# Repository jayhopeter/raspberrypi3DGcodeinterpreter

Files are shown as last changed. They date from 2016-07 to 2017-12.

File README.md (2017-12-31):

# raspberrypi3DGcodeinterpreter
Work in Process code for a completely RaspberryPi controlled RepRap.  Thanks to Xiang Zhai for supplying his laser engraver gcode interpreter which I am using as a starting point for this project.

We have this system working with the code(It can be done without an Ardruino!).  Prints are not perfect but pretty close at this point. I will be updating the design to use an ADC chip instead of the ganky 555 timer high pulse measuring method I'm using now.

I will be uploading the Eagle schematic and soon as I get it cleaned up and matching the recent changes.

Current limitations:

- For testing purposing full stepping the motors is the only option. I'm not using stepsticks, I built my own controllers using L298 Quad-HBridge chips.  I also use a Hex inverter(NOT-GATE) to allow control with only 2 GPIOs instead of 4 for each motor, the trade off is that you can only full step your motors.  If you want to try without the NOT-GATE method or with half stepping you can change the commented out lines in the Bipolar Stepper Motor Class file.

*Update - Work has begun on a Windows IoT version of this software which will be written in C#.  I will link to it when it's published.

*Update - Will not be working on the Windows IoT version until the Microsoft makes the IoT OS more user friendly.

*Update - Bahamuttg is working on C++ version of the software with a complete UI in Qt C++ called PiRinter3D.  This will be for an all in one 3D Printing solution using the Raspberry PI(design, slicing, and printing).

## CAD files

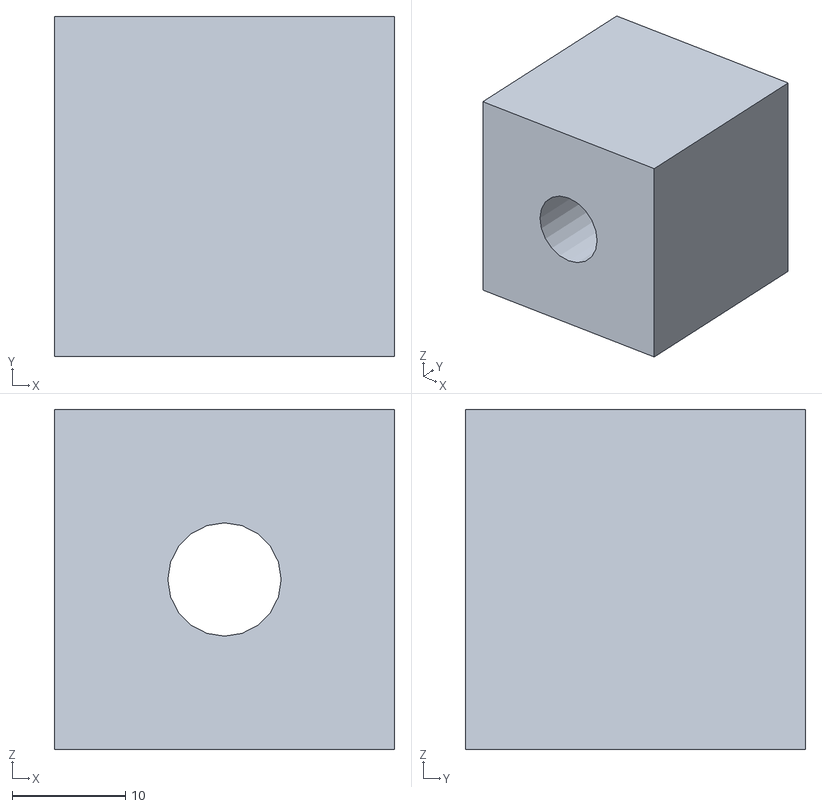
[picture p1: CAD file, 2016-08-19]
Gcode/testcube.STL
30.0 x 30.0 x 30.0

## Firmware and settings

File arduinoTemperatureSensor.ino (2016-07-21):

int sensorPin = A0;    // select the input pin for the potentiometer
int ledPin = 13;      // select the pin for the LED
int sensorValue = 0;  // variable to store the value coming from the sensor
int ctr = 1;
int sensortotal=0;
int maxTemp = 450;

void setup() {
  // declare the ledPin as an OUTPUT:
  pinMode(ledPin, OUTPUT);  
  Serial.begin(9600); 
}

void loop() {
  if (Serial.available() > 0) {
   // read the incoming tempsetting
   maxTemp = Serial.read();
  }
  // read the value from the sensor:
  sensorValue = analogRead(sensorPin);    
  // turn the ledPin on
  //Serial.println(sensorValue);
  
  sensortotal += sensorValue;
  //Serial.println(sensortotal);
  if( ctr % 10 == 0)
  {
    
  sensorValue = sensortotal/10;
  //Serial.println(sensorValue);
  //the quick way
  // map it to the range of the analog out:
  int outputValue = 0;
  outputValue = map(sensorValue, maxTemp-20, maxTemp, 0, 255);
  // change the analog out value:
  analogWrite(ledPin, outputValue);
  
  //the dumb way
//  if(sensorValue <= maxTemp-20)
//  {
//    analogWrite(ledPin,0);
//  }
//  else if(sensorValue > maxTemp-20 && sensorValue <= maxTemp-17)
//  {
//    analogWrite(ledPin,30);
//  }
//  else if(sensorValue > maxTemp-17 && sensorValue <= maxTemp-14)
//  {
//    analogWrite(ledPin,60);
//  }
//  else if(sensorValue > maxTemp-14 && sensorValue <= maxTemp-11)
//  {
//    analogWrite(ledPin,100);
//  }
//  else if(sensorValue > maxTemp-11 && sensorValue <= maxTemp-8)
//  {
//    analogWrite(ledPin,125);
//  }
//  else if(sensorValue > maxTemp-8 && sensorValue <= maxTemp-5)
//  {
//    analogWrite(ledPin,170);
//  }
//  else if(sensorValue > maxTemp-5 && sensorValue<= maxTemp)
//  {
//    analogWrite(ledPin,205);
//  }
//  else if(sensorValue > maxTemp)
//  {
//    analogWrite(ledPin,250);
//  }
  
  sensortotal = 0;
  ctr = 0;
  }
  ctr += 1;
  delay(20);                  
}

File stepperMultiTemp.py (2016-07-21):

#!/usr/bin/env python
# -*- coding: utf-8 -*-

# vim: tabstop=4 expandtab shiftwidth=4 softtabstop=4

# For input pins on motor controller using two GPIOs per motor.
# This tested with a TI 7404 HEX INVERTER and with 2 TI 754410
# and 2 L298N Dual H Bridges


import RPi.GPIO as GPIO
import time
GPIO.setmode(GPIO.BCM)

motor1_A_pin = 17
motor1_B_pin = 4
motor2_A_pin = 23
motor2_B_pin = 18
motor3_A_pin = 24
motor3_B_pin = 25
motor4_A_pin = 27
motor4_B_pin = 22

ExtHeat = 10
ExtTherm = 11
HeatBed = 9
HeatTherm = 8

MAXSTEPS = 23
TOTALDISTANCE = 35
PERSISION = TOTALDISTANCE/MAXSTEPS


GPIO.setup(motor1_A_pin, GPIO.OUT)
GPIO.setup(motor1_B_pin, GPIO.OUT)
GPIO.setup(motor2_A_pin, GPIO.OUT)
GPIO.setup(motor2_B_pin, GPIO.OUT)
GPIO.setup(motor3_A_pin, GPIO.OUT)
GPIO.setup(motor3_B_pin, GPIO.OUT)
GPIO.setup(motor4_A_pin, GPIO.OUT)
GPIO.setup(motor4_B_pin, GPIO.OUT)
GPIO.setup(ExtHeat, GPIO.OUT)
GPIO.setup(HeatBed, GPIO.OUT)
GPIO.setup(ExtTherm, GPIO.IN)
GPIO.setup(HeatTherm, GPIO.IN)

def forwardMotor1(delay, steps):  
  for i in range(0, steps):
    setStep1(1, 1)
    time.sleep(delay)
    setStep1(0, 1)
    time.sleep(delay)
    setStep1(0, 0)
    time.sleep(delay)
    setStep1(1, 0)
    time.sleep(delay)  

def backwardsMotor1(delay, steps):  
  for i in range(0, steps):
    setStep1(1, 0)
    time.sleep(delay)
    setStep1(0, 0)
    time.sleep(delay)
    setStep1(0, 1)
    time.sleep(delay)
    setStep1(1, 1)
    time.sleep(delay)

def forwardMotor2(delay, steps):  
  for i in range(0, steps):
    setStep2(1, 1)
    time.sleep(delay)
    setStep2(0, 1)
    time.sleep(delay)
    setStep2(0, 0)
    time.sleep(delay)
    setStep2(1, 0)
    time.sleep(delay)  

def backwardsMotor2(delay, steps):  
  for i in range(0, steps):
    setStep2(1, 0)
    time.sleep(delay)
    setStep2(0, 0)
    time.sleep(delay)
    setStep2(0, 1)
    time.sleep(delay)
    setStep2(1, 1)
    time.sleep(delay)

def forwardMotor3(delay, steps):  
  for i in range(0, steps):
    setStep3(1, 1)
    time.sleep(delay)
    setStep3(0, 1)
    time.sleep(delay)
    setStep3(0, 0)
    time.sleep(delay)
    setStep3(1, 0)
    time.sleep(delay)  

def backwardsMotor3(delay, steps):  
  for i in range(0, steps):
    setStep3(1, 0)
    time.sleep(delay)
    setStep3(0, 0)
    time.sleep(delay)
    setStep3(0, 1)
    time.sleep(delay)
    setStep3(1, 1)
    time.sleep(delay)

def forwardMotor4(delay, steps):  
  for i in range(0, steps):
    setStep4(1, 1)
    time.sleep(delay)
    setStep4(0, 1)
    time.sleep(delay)
    setStep4(0, 0)
    time.sleep(delay)
    setStep4(1, 0)
    time.sleep(delay)  

def backwardsMotor4(delay, steps):  
  for i in range(0, steps):
    setStep4(1, 0)
    time.sleep(delay)
    setStep4(0, 0)
    time.sleep(delay)
    setStep4(0, 1)
    time.sleep(delay)
    setStep4(1, 1)
    time.sleep(delay)

def setStep1(w1, w3):
  GPIO.output(motor1_A_pin, w1)
  GPIO.output(motor1_B_pin, w3)

def setStep2(w1, w3):
  GPIO.output(motor2_A_pin, w1)
  GPIO.output(motor2_B_pin, w3)

def setStep3(w1, w3):
  GPIO.output(motor3_A_pin, w1)
  GPIO.output(motor3_B_pin, w3)

def setStep4(w1, w3):
  GPIO.output(motor4_A_pin, w1)
  GPIO.output(motor4_B_pin, w3)

def writeToLog(outputText):
  with open('tempout.txt','a') as f:
    f.write(outputText)
  print outputText

def sampleHeaters(extThermPin,heatbeadThermPin):
  sampleHeaterDutyCycle(extThermPin, "Extruder")
  sampleHeaterDutyCycle(heatbeadThermPin, "Heated Bed")

def sampleHeaterDutyCycle(pin, name):
  writeToLog("Testing "+ name +" Temperature\n");
  counter = 0
  GPIO.wait_for_edge(pin, GPIO.RISING)
  while GPIO.input(pin) == GPIO.HIGH:
    counter += 1
    time.sleep(0.001)
  writeToLog(name+ " Thermistor 555 Timer High Pulse Time "+ str(counter)+"\n")
  
writeToLog('Starting RepRap test Motor and temperature reading program ' + str(time.time())+ '\n')

writeToLog("Turn on Extruder...\n");
GPIO.output(ExtHeat, 1)
writeToLog("Turn on HeatBed...\n");
GPIO.output(HeatBed, 1)

#test X Axis
delay = raw_input("X Axis Delay between steps (milliseconds)?")
steps = raw_input("How many steps forward X? ")
forwardMotor1(int(delay) / 1000.0, int(steps))
steps = raw_input("How many steps backwards X? ")
backwardsMotor1(int(delay) / 1000.0, int(steps))

#GPIO.output(ExtHeat, 0)
#GPIO.output(HeatBed, 1)
#Sample heaters
sampleHeaters(ExtTherm,HeatTherm) 

#test Y Axis
delay = raw_input("Y Axis Delay between steps (milliseconds)?")
steps = raw_input("How many steps forward Y? ")
forwardMotor2(int(delay) / 1000.0, int(steps))
steps = raw_input("How many steps backwards Y? ")
backwardsMotor2(int(delay) / 1000.0, int(steps))

#GPIO.output(HeatBed, 0)
#GPIO.output(ExtHeat, 1)
sampleHeaters(ExtTherm,HeatTherm)

#test Z Axis
delay = raw_input("Z Axis Delay between steps (milliseconds)?")
steps = raw_input("How many steps forward Z? ")
forwardMotor3(int(delay) / 1000.0, int(steps))
steps = raw_input("How many steps backwards Z? ")
backwardsMotor3(int(delay) / 1000.0, int(steps))

#GPIO.output(ExtHeat, 0)
#GPIO.output(HeatBed, 1)
sampleHeaters(ExtTherm,HeatTherm)

#test Extruder Motor
delay = raw_input("Extruder Motor Delay between steps (milliseconds)?")
steps = raw_input("How many steps forward Ext? ")
forwardMotor4(int(delay) / 1000.0, int(steps))
steps = raw_input("How many steps backwards Ext? ")
backwardsMotor4(int(delay) / 1000.0, int(steps))

sampleHeaters(ExtTherm,HeatTherm)
writeToLog("Turn off Extruder...\n");
GPIO.output(HeatBed, 0)
writeToLog("Turn off Heat Bed...\n");
GPIO.output(ExtHeat, 0)
writeToLog("Cleaing GPIOs...\n");
GPIO.cleanup()
writeToLog("Exiting...\n");

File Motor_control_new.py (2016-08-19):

import RPi.GPIO as GPIO
import time
from Bipolar_Stepper_Motor_Class_new import Bipolar_Stepper_Motor
from numpy import abs,sqrt,float

def sign(a): #return the sign of number a
    if a > 0:
        return 1
    elif a < 0:
        return -1
    else:
        return 0

def Single_Motor_Step(stepper, step, speed=100):
#   control stepper motor 1 and 2 simultaneously
#   stepper1 and stepper2 are objects of Bipolar_Stepper_Motor class
#   direction is reflected in the polarity of [step1] or [step2]

    dir1 = sign(step)  #get dirction from the polarity of argument [step]

    step = abs(step)

    #T = step / speed      #total time
    #dt = T / step                #time delay every micro_step
    stepper.move(dir1,step,1/speed) # don't pass dt here, not working for Z Axis have to figure out why?
    
    return 0
    
def Motor_Step(stepper1, step1, stepper2, step2, speed):
#   control stepper motor 1 and 2 simultaneously
#   stepper1 and stepper2 are objects of Bipolar_Stepper_Motor class
#   direction is reflected in the polarity of [step1] or [step2]

    dir1 = sign(step1)  #get dirction from the polarity of argument [step]
    dir2 = sign(step2)
    
    step1 = abs(step1)
    step2 = abs(step2)
 
    iterator = max(step1, step2)
            
    T = sqrt(step1 ** 2 + step2 ** 2) / speed      #total time
    dt = T / (step1 + step2)                #time delay every micro_step

    #Setup the Ratio Values.
    M1Ratio = float(step1) / float(iterator)
    M2Ratio = float(step2) / float(iterator)
 
    M1Holder = float(0)
    M2Holder = float(0)

    M1ctr = 0
    M2ctr = 0
    
    for i in range(0, iterator):
        M1Holder = float(M1Holder) + float(M1Ratio)
        M2Holder = float(M2Holder) + float(M2Ratio)

        if(M1Holder >= 1):
            M1Holder = float(M1Holder) - 1
            stepper1.move(dir1,1,dt)
            M1ctr = M1ctr + 1

        if(M2Holder >= 1):
            M2Holder = float(M2Holder) - 1
            stepper2.move(dir2,1,dt)
            M2ctr = M2ctr + 1

	#clean-up any missed or over steps...
    if(M1ctr < step1):
            stepper1.move(dir1,1,dt)
    if(M2ctr < step2):
            stepper2.move(dir2,1,dt)
   	#overstep?
    if(M1ctr > step1):
            stepper1.move(dir1 * -1,1,dt)
    if(M2ctr > step2):
            stepper2.move(dir2 * -1,1,dt)
    return 0

def Motor_StepThree(stepper1, step1, stepper2, step2,stepper3,step3, speed):
#   control stepper motor 1 and 2 simultaneously
#   stepper1 and stepper2 are objects of Bipolar_Stepper_Motor class
#   direction is reflected in the polarity of [step1] or [step2]
    
    dir1 = sign(step1)  #get dirction from the polarity of argument [step]
    dir2 = sign(step2)
    dir3 = sign(step3)
    
    step1 = abs(step1)
    step2 = abs(step2)
    step3 = abs(step3)
    
    iterator = max(step1, step2, step3)
            
    T = sqrt(step1 ** 2 + step2 ** 2) / speed      #total time
    dt = T / (step1 + step2)                #time delay every micro_step

    #Setup the Ratio Values.
    M1Ratio = float(step1) / float(iterator)
    M2Ratio = float(step2) / float(iterator)
    M3Ratio = float(step3) / float(iterator)

    M1Holder = float(0)
    M2Holder = float(0)
    M3Holder = float(0)

    M1ctr = 0
    M2ctr = 0
    M3ctr = 0
    
    for i in range(0, iterator):
        M1Holder = float(M1Holder) + float(M1Ratio)
        M2Holder = float(M2Holder) + float(M2Ratio)
        M3Holder = float(M3Holder) + float(M3Ratio)

        if(M1Holder >= 1):
            M1Holder = float(M1Holder) - 1
            stepper1.move(dir1,1,dt)
            M1ctr = M1ctr + 1

        if(M2Holder >= 1):
            M2Holder = float(M2Holder) - 1
            stepper2.move(dir2,1,dt)
            M2ctr = M2ctr + 1

        if(M3Holder >= 1):
            M3Holder = float(M3Holder) - 1
            stepper3.move(dir3,1)
            M3ctr = M3ctr + 1

	#clean-up any missed or over steps...
    if(M1ctr < step1):
            stepper1.move(dir1,1,dt)
    if(M2ctr < step2):
            stepper2.move(dir2,1,dt)
    if(M3ctr < step3):
            stepper3.move(dir3,1)
	#overstep?
    if(M1ctr > step1):
            stepper1.move(dir1 * -1,1,dt)
    if(M2ctr > step2):
            stepper2.move(dir2 * -1,1,dt)
    if(M3ctr > step3):
            stepper3.move(dir3 * -1,1)
    return 0

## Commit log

2015-05-26 Create Thermistor555TimerTempChart.txt
    This is temperature chart for a Honeywell 135-103LAF-J01 10K thermistor. Because the Raspberry PI has no analog read I'm using a 555 timer in astable mode and measuring the output pulse high time(poo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
2015-05-30 adding temperature debug lines
2015-06-03 Added Heatbed code
2015-06-05 Fan off
2015-06-07 temperature sensing test script
2015-06-08 More Temperature work
2015-06-09 Still More Temperature code
2015-06-18 sample Gcode file
2015-06-18 Truncated GCode sample file
    Too big for Github includes just the first few layers of the print, for
    testing purposes
2015-06-18 added Extruder code to circular interpolation
2015-07-12 fixed syntax error
    fixed syntax error
    [3DGcode_executer.py]
2015-07-21 Revert "fixed syntax error"
    This reverts commit f5f5b03f4515095ae7b2197219cb19ae85f0164f.
    [3DGcode_executer.py]
2015-11-01 updated temperature issues
2015-11-15 indent error in file
    [3DGcode_executer.py]
2015-11-15 Fixed bug with average
    [3DGcode_executer.py]
2016-06-13 created VS sln and fixed some formatting issues
    [3DGcode_executer.py, Motor_control_new.py]
2016-07-14 added Gcode samples
2016-07-14 worked on issues with slow movement
    [3DGcode_executer.py, Motor_control_new.py]
2016-07-15 Small fixes with new TODOs
    [3DGcode_executer.py, Motor_control_new.py]
2016-07-15 More and More Fixes
    [3DGcode_executer.py]
2016-07-22 Adjust temp table file
    Adjusting temp tables, in practice the high times read lower than 555
    timer math works out.
2016-07-22 Adjusting temp tables
    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
2016-07-28 turning extruder resolution way up so we don't get filament jamming
    turning extruder resolution way up so we don't get filament jamming
    [3DGcode_executer.py]
2016-07-29 Resolution adjustment and a bug fix
    Resolution adjustment and a bug fix
    [3DGcode_executer.py, Motor_control_new.py]
2016-08-02 Readjusted temperature and fixed some settings and motor movement issues
    [3DGcode_executer.py, Motor_control_new.py]
2016-08-03 Updated and re- factored python code.
    Motor controller updated with cleaner more efficient move algorithms.
    Stepper motor class now has a minimum delay time check, and the G-code
    interpreter is better calibrated.
2016-08-10 Removed unneed conversion for single motor move
2016-08-16 Starting change over from 555 timer high pluse to ADC temp control
    Starting change over from 555 timer high pluse to ADC temp control
2016-08-17 completed code conversion to use ADC for temp readings
2016-08-18 Pin reassignment and temp disabling of homing axis Gcode
2016-08-18 Pins set back to normal. Updated temperature check settings
    Pins set back to normal. Decreased temperature check interval and set
    tighter temperature range(prev +/- 5, now +/- 2)
    [3DGcode_executer.py, Bipolar_Stepper_Motor_Class_new.py]
2016-08-19 adding test cube stl file
    adding test cube stl file
    [testcube.STL]
2016-08-19 modify cube with 3mm radius tap
    [testcube.STL]
2016-08-19 changed tap to 5mm radius
    [testcube.STL]
2016-09-12 Fixed possible divide by zero error on ADC read
    Fixed possible divide by zero error on ADC read
    [3DGcode_executer.py]
